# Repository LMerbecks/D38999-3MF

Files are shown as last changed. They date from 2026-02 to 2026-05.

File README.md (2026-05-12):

# D38999-3MF

Mated connector system shell size C

In this repository we developed a MIL-DTL-38999 style
connector system that can be 3D-printed. It was inspired by
[this thing](https://www.thingiverse.com/thing:3129731) by
[fdavies](https://www.thingiverse.com/fdavies/designs). The
connector system uses Molex
[1561](https://www.molex.com/en-us/products/series-chart/1561)
and
[1560](https://www.molex.com/en-us/products/series-chart/1560)
stamped circular crimp contacts. 
> Note this connector system
does not claim full compatibility and compliance with the
standards mentioned. 

## Introduction

MIL-DTL-38999 connectors are widely adopted in the aerospace
industry. You may take a look at the different variants at
leading manufacturers like [Amphenol
Aerospace](https://www.amphenol-aerospace.com/products/mil-dtl-38999-connectors)
or [ITT Cannon](https://www.ittcannon.com/38999-style). A
really common type is the type III variant which features a
triple start thread for mating.

These connectors are durable,
[scoop-proof](https://www.microwaves101.com/encyclopedias/scoop-proof-connectors)
and satisfying to work with. However, they are also
expensive and thus not an option for small or hobby
projects. This project aims to change that by making these
connectors accessible to a broader audience via additive
manufacturing. Surely these versions will never match the
characteristics of the industrial versions but they make the
D38999 concept with almost all advantages accessible to more people than just industry
branches. 

## Specifications and Features

- 336 unique connector systems in nine different sizes
- M3 bolt holes for mounting of receptacle
- Polarized and scoop proof
- Up to 61 contacts per connector
- 1.25 turns to fully lock
- cheap and accessible contacts <0.10€ per contact
- mated length 30mm
- max footprint 46 x 46 mm

## Usage

A connector system consists of a receptacle and a plug. You
can mate the plug to the receptacle by turning the plug on
the receptacle until the keys align. The connectors should
move closer together at that point. Then you pull the
connection closed by rotating the coupling nut on the plug
clockwise. Turn the coupling nut until the groove on the
receptacle is covered by the nut. To release the connector rotate the coupling nut
counter-clockwise.

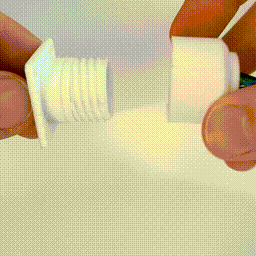
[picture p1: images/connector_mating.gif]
Animation showing mating of connectors


*Animation of
connectors mating*

To build a connector system you have to 
1. choose shells, and
2. choose an insert arrangement. 

We will go into more detail of these two steps in the
following sections.

### Shells

Shells are the frames of the connector system that in turn
hold the fixture (insert) that locates the electrical
contacts. They are the outermost part of the connector and
thus are called shells. Their primary function is the
mechanical mating.

The shells are characterized by part numbers in this format:

`D38999-<ST>A<S><XXX><K>`
where
- `D38999` is the connector series code,
- `<ST>` is the shell type,
- `A` is the service class for additive manufacturing
  (choosen by us)
- `<S>` is the size code,
- `<XXX>` is the insert arrangement identifier, and
- `<K>` is the keying code.

The individual parts for the part number are addressed int
he following sections

#### Shell types

There are two shell types supported at the moment: 
- straight plugs (code `26`)
  Straight plug part code D38999-26ACXXXN *A D38999-26ACXXXN
  shell*
- wall mount receptacles (code `20`)
  Wall mount receptacle part code D38999-20ACXXXN *A
  D38999-20ACXXXN shell*
  
#### Shell sizes

The shell size determines only the diameter of a
shell. The length i.e. the dimension in direction of the
mating axis is not affected by this. 

The available shell sizes are listed in the following table.
Note that there are military and civil codes for the shell
size. For the shells the military code is used in this repository.

| military code | `A` | `B` | `C` | `D` | `E` | `F` | `G` | `H` | `J` |
| ---| - | - | - | - | - | - | - | - | - |
| civil code |` 9` | `11` | `13` | `15` | `17` | `19` | `21` | `23` | `25` |

Shell size B and C plugs*Different shell size
plugs: size B on the left and size C on the right*

In general larger connectors can hold inserts with more electrical contacts.

#### Shell keying

Shells of the same size can have different keying options.
Only plugs and receptacles with matching **keying options and
shell sizes** can
mate.

This mechanically prevents mating of wrong connector pairs.
The behavior is achieved by having five keys or keyways around the plug
or receptacle, respectively, in a unique pattern for every
keying option. Note that the exact pattern can also change depending
on the shell size.

The available keying options are: 

`N, A, B, C, D, E`

Here option `N` is the most common "normal" option.

#### Building shell part numbers

In conclusion, to build a shell part number you 
1. select the shell type,
2. select the shell size,
3. select the shell keying.

The CAD models for the shells are found in the `/models/`
directory. They are modeled using [FreeCAD](https://www.freecad.org).

### Inserts

Inserts are the inner parts of the connector system that
locate the electrical contacts. The insert arrangement part
numbers look like this:

`<SZ>-<IA><G>` where
- `<SZ>` is the shell size, 
- `<IA>` is the insert arrangement, and
- `<G>` is the gender.

#### Shell size

The shell size determines which shell sizes the insert can
be used with. It primarily determines the outside diameter
of the insert. 

All shell sizes have at least two insert arrangements
available right now.

#### Insert arrangement

The insert arrangement determines how the contacts are
arranged in the insert. The code hints how many contacts
can find place in a insert. This is not always the case.

The following insert arrangements (combined with the shell
size) are available

| Insert Arrangement Name | Number of contacts | Tested |
|---|---| --- |
| 9-3 | 3 | :white_check_mark: |
| 9-98 | 3 | :white_check_mark: |
| 11-2 | 2 | :white_check_mark: |
| 11-4 | 4 | :white_check_mark: |
| 11-5 | 5 | :white_check_mark: |
| 11-98 | 6 | :white_check_mark: |
| 11-99 | 7 | :white_check_mark: |
| 13-4 | 4 | :white_check_mark: |
| 13-8 | 8 | :white_check_mark: |
| 13-98 | 10 | :white_check_mark: |
| 15-5 | 5 | :white_check_mark: |
| 15-15 | 15 | :white_check_mark: |
| 15-18 | 18 | :white_check_mark: |
| 15-19 | 19 | :white_check_mark: |
| 15-97 | 12 | :white_check_mark: |
| 17-6 | 6 | :x: |
| 17-8 | 8 | :x: |
| 17-11 | 11 | :x: |
| 17-26 | 26 | :x: |
| 19-11 | 11 | :x: |
| 19-28 | 28 | :x: |
| 19-30 | 30 | :x: |
| 19-32 | 32 | :x: |
| 21-11 | 11 | :x: |
| 21-16 | 16 | :x: |
| 21-24 | 24 | :x: |
| 21-25 | 25 | :x: |
| 21-27 | 27 | :x: |
| 21-29 | 26 | :x: |
| 21-39 | 39 | :x: |
| 21-75 | 4 | :x: |
| 21-76 | 4 | :x: |
| 23-21 | 21 | :x: |
| 23-32 | 32 | :x: |
| 23-34 | 34 | :x: |
| 23-36 | 36 | :x: |
| 23-53 | 53 | :x: |
| 23-55 | 55 | :x: |
| 23-97 | 16 | :x: |
| 23-99 | 11 | :x: |
| 25-4 | 56 | :x: |
| 25-8 | 8 | :x: |
| 25-10 | 8 | :x: |
| 25-11 | 11 | :x: |
| 25-19 | 19 | :x: |
| 25-20 | 30 | :x: |
| 25-21 | 30 | :x: |
| 25-24 | 24 | :x: |
| 25-29 | 29 | :x: |
| 25-37 | 37 | :x: |
| 25-43 | 43 | :x: |
| 25-46 | 46 | :x: |
| 25-47 | 46 | :x: |
| 25-61 | 61 | :x: |
| 25-90 | 46 | :x: |
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

Where possible standard insert arrangements are used as
specified in MIL-STD-1560C.

Not all inserts have been tested yet. Feel free to
contribute here.

#### Gender

The gender determines whether the insert is designed to hold
pin contacts (Molex 1560, code `P`) or socket contacts
(Molex 1561, code `S`). 

This impacts the length of the insert but any gender of
insert can be installed in any receptacle or plug as long as
the shell size matches. 

In general, the plug that can be moved around gets the socket insert because these
contacts are less exposed and less prone to damage. The
receptacle receives the pin insert.

#### Building insert part numbers

In conclusion, to build a part number of an insert you need
to
1. choose the shell size, 
2. choose how many contacts you need,
3. choose the gender.

Most of the time you'll want to get both genders of an
insert, however.

Insert are automatically generated through scripts located
in `/scripts/`. The base models are designed in
[FreeCAD](https://www.freecad.org) and are located in `/models/` 

## Manufacturing and Assembly

There are a few important notices you should follow when
building your connector system. These steps are described in
the following section.

### Manufacturing

[Download](https://www.printables.com/@leandermerbe_4394823/collections/3171811) or [export](/scripts/) the model files and slice them. We had
good results with 0.2mm layer height. Print the shells in
the orientation shown in the figure below.

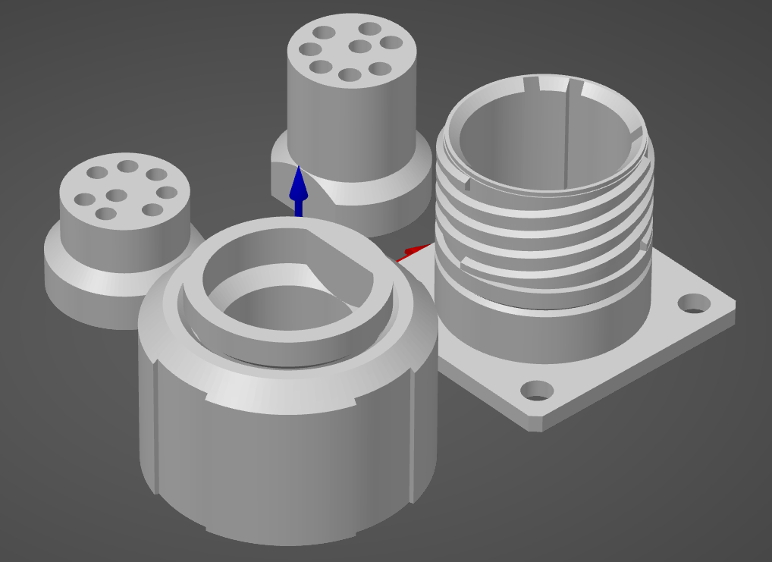
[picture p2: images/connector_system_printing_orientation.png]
Print orientation shells
*Recommended
printing
orientation for plug, receptacle, and inserts.*

The plug is a two body part that is print in place.

> **IMPORTANT**
> 
> Disable support generation for the plug shell. You will
> not be able to remove the support.

The print time varies and can take up to multiple hours.

### Assembly

After the print is finished remove the parts. You can now
turn the coupling nut on the plug shell to break it loose
from the core. If this does not work right away you can use
a matching receptacle to fix the core in place and get a
better grip on it. 

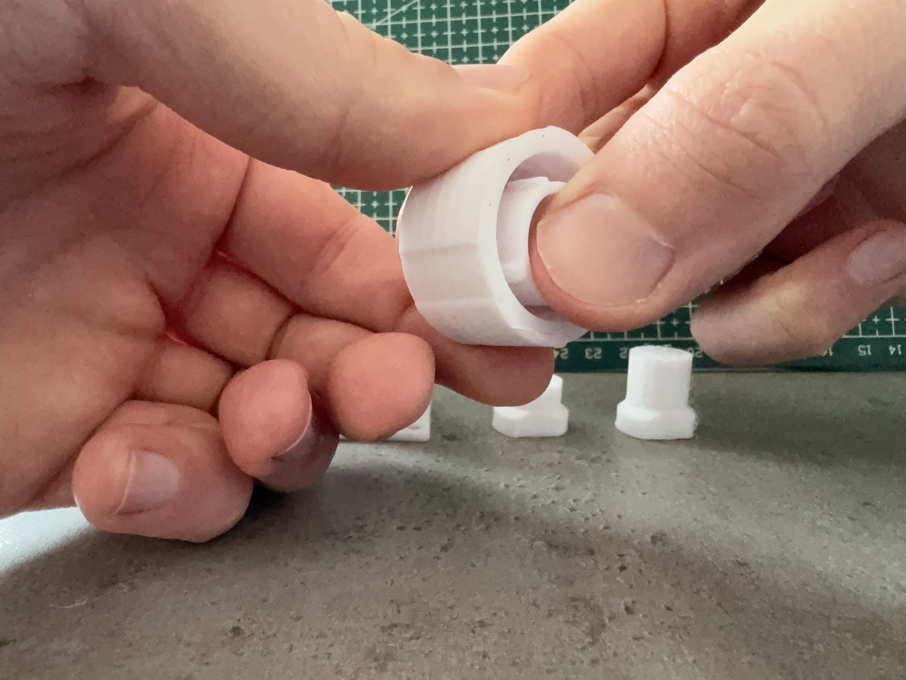
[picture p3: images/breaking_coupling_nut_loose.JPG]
Breaking the coupling nut of the plug loose
*Breaking the
coupling nut loose from the plug core.*

Now you clean the insert contact holes with a 2mm drill.
This removes any strings or seams formed during
manufacturing. You may use a cordless drill to speed up the
process. 

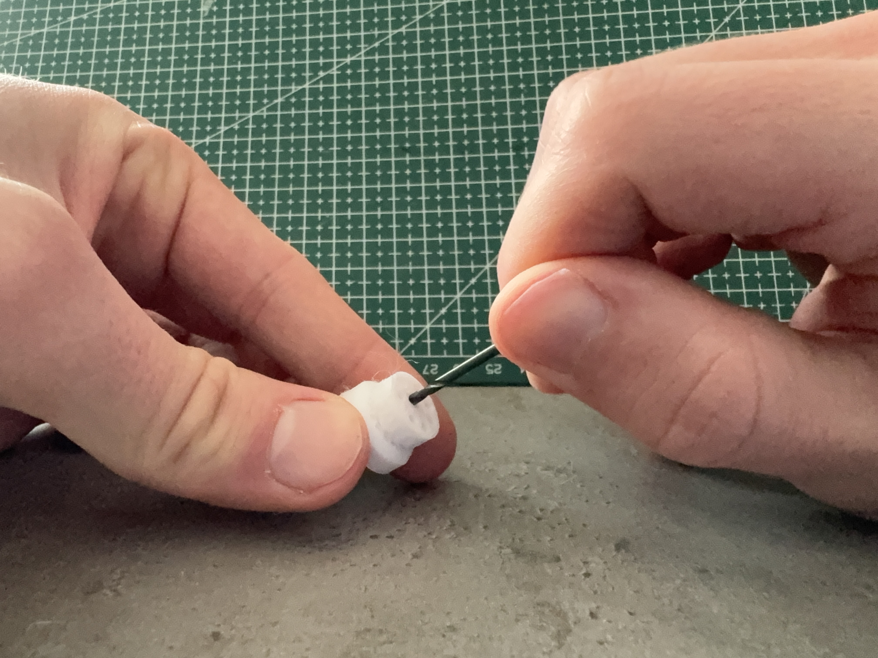
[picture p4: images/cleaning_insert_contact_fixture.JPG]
Cleaning contact holes
*Cleaning
the contact holes with a 2mm drill*

Next, insert the inserts into the shells. Depending on the
fit you may want to glue them in permanently with superglue
or shim them with e.g. a piece of paper.

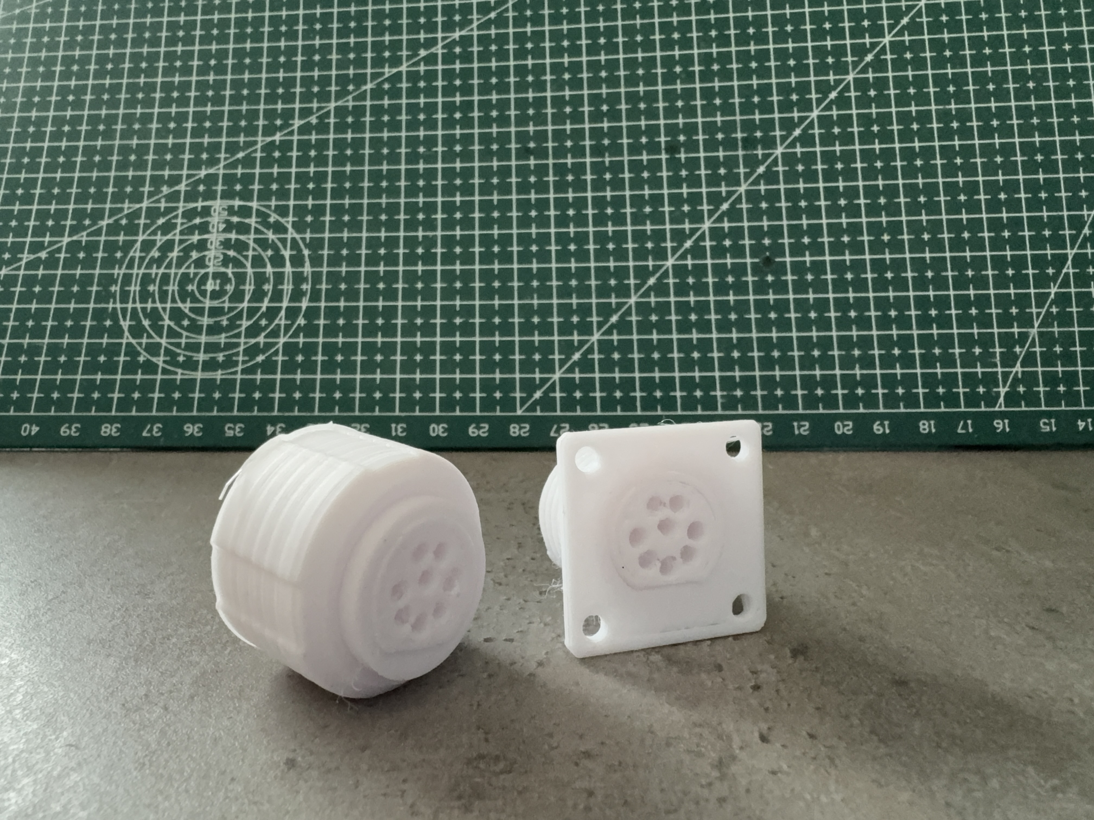
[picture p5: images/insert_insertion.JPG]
Insertion of inserts
*Insertion of inserts*

Afterward, crimp the cables/wires with the Molex 1560 or
1561 contacts and insert the contacts into the appropriate
insert depending on the gender. You may use a pair of pliers
here to exert more force but the contact should go in rather
smoothly. Insert the contacts into the insert so far that
the contact is just barely inside of the insert.

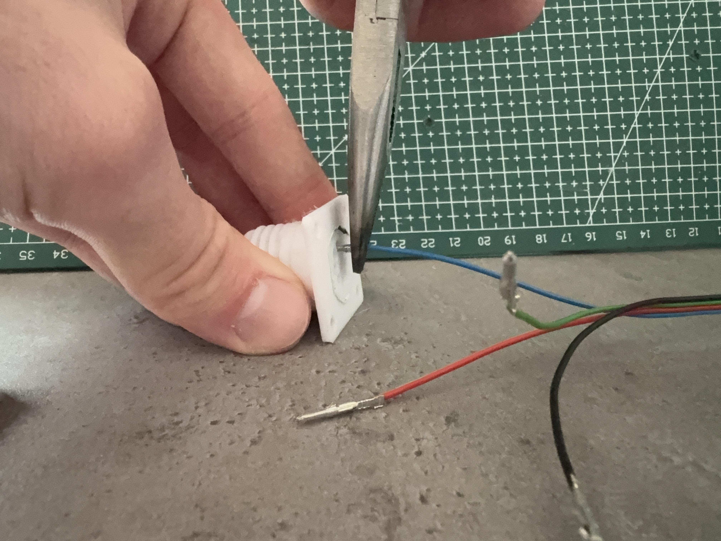
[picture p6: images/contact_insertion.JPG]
Installing the contacts

*Installing crimp contacts*

At last, you have your completed connector system:
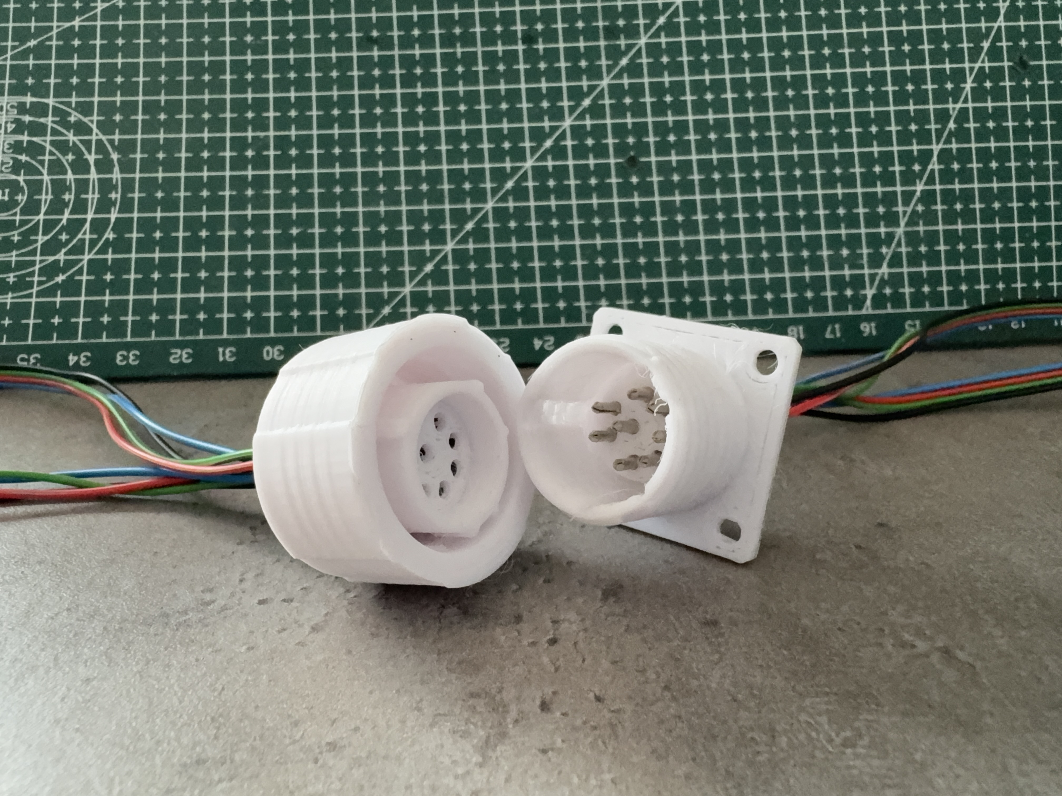
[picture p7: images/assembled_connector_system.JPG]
Completed connector system
*Completed
connector system*

## Developer Instructions

So you want to have a deeper look into this repository and
how the CAD files are working? We look at three parts here
1. the CAD files,
2. exporting the models, and
3. generating inserts.

### CAD files

The CAD files are developed with
[FreeCAD](https://www.freecad.org/) and split into only four
files
1. a file for the receptacle `/models/D38999-26AXXXXX.FCStd`,
2. a file for the plug `/models/D38999-20AXXXXX.FCStd`,
3. a file for the pin inserts `/models/PinInserts.FCStd`, and 
4. a file for the socket inserts. `/models/SocketInserts.FCStd`

Historically, the receptacle and plug files contained the
geometry of the inserts. When automation was deployed in
the insert generation this was changed.

The models are parametrized and the shell size and keying
option can be changed by accessing the corresponding attributes of the
`Receptacle_core` or `Plug_core` parts in the property
inspector. Note that keying options vary for shell sizes and
are thus given with the keying code and all applicable shell
sizes afterward. 

The insert models are generated automatically and also
exported in one go. The models for them contain the
base body that fits into the shell and a tool body that is
used to form the contact fixtures for all inserts. 

### Export

As there are a lot of geometries to export, this process is
automated with scripts located in `/scripts/`. The export is split into different procedures for
inserts and shells. It uses python and the python interface
of FreeCAD. Before starting you need to install
dependencies: 
```bash
> cd ./scripts/
> python3 -m venv .venv
> source .venv/bin/activate
> pip install -r requirements.txt 
> # this is for the export using FreeCAD python
> freecad.pip install -r requirements.txt
```

Then you can start the export which is described for shells
and inserts separately.

#### Shells

To export shells we use the `export_shells.py` script. It
changes the keying option and shell size of both shell
models, recomputes the model and exports a `.3mf` to
`/output/`. Note that the export can take up to six minutes.

To run it type:

```bash
> cd scripts
> freecad.cli export_shells.py
```

After the run your output directory should look like this (abbreviated).

```bash
> tree ./output/
./output/
├── plugs
│   ├── A
│   │   ├── D38999-26AAXXXA.3mf
│   │   ├── D38999-26AAXXXB.3mf
│   │   ├── D38999-26AAXXXC.3mf
│   │   ├── D38999-26AAXXXD.3mf
│   │   ├── D38999-26AAXXXE.3mf
│   │   └── D38999-26AAXXXN.3mf
│   ├── B
│   │   └── ...
│   ├── C
│   │   └── ...
│   ├── D
│   │   └── ...
│   ├── E
│   │   └── ...
│   ├── F
│   │   └── ...
│   ├── G
│   │   └── ...
│   ├── H
│   │   └── ...
│   └── J
│   │   └── ...
└── wall_mount_receptacles
    ├── A
    │   ├── D38999-20AAXXXA.3mf
    │   ├── D38999-20AAXXXB.3mf
    │   ├── D38999-20AAXXXC.3mf
    │   ├── D38999-20AAXXXD.3mf
    │   ├── D38999-20AAXXXE.3mf
    │   └── D38999-20AAXXXN.3mf
    ├── B
    │   └── ...
    ├── C
    │   └── ...
    ├── D
    │   └── ...
    ├── E
    │   └── ...
    ├── F
    │   └── ...
    ├── G
    │   └── ...
    ├── H
    │   └── ...
    └── J
        └── ...
```

The geometries are exported sorted by shell type, shell size
and then keying option. 

#### Inserts

The insert export is a two step process. First the
dimensions are extracted from the MIL-STD-1560 pdf. This is
done with python via the following command. It may take a
few minutes to run. 

```bash
> cd scripts
> python3 extract_dimension_tables.py
```
The script scans the standard for any inserts for the D38999
Series III connectors that have no contacts smaller than
size 20. This ensures the Molex 1560 and 1561 contacts fit
into the insert. 

After the command the `/dimensions/` directory should
look like this:

```bash
tree dimensions/
dimensions/
├── 11-2_contact_positions.csv
├── 11-4_contact_positions.csv
├── ...
├── applicable_insert_arrangements.csv
├── MIL-STD-1560C_CHG-2.pdf
└── overview.csv
```

The `*_contact_positions.csv` files contain the positions
for the contacts of every insert-arrangement. The
`applicable_insert_arrangements.csv` is a simple list of all
insert arrangements that are available for this connector
series. Likewise `overview.csv` lists the available insert
arrangements with the available amounts of contacts, as in
the table above. 

Next, the FreeCAD CLI is used to generate all inserts that
are in the `dimensions` directory. Note that you may define
custom insert arrangements with unique file names following
the naming convention. This script can take a few minutes to
run. 

```bash
> cd scripts
> freecad.cli insert_generator.py
```

Now the `output` directory should contain all exported
insert models. 

```bash
> tree output
output
└── inserts
    ├── A
    │   ├── 9-3P.3mf
    │   ├── 9-3S.3mf
    │   ├── 9-98P.3mf
    │   └── 9-98S.3mf
    ├── B
    │   └── ...
    ├── C
    │   └── ...
    ├── D
    │   └── ...
    ├── E
    │   └── ...
    ├── F
    │   └── ...
    ├── G
    │   └── ...
    ├── H
    │   └── ...
    └── J
        └── ...
```

## Credits

This project was inspired by [this
thing](https://www.thingiverse.com/thing:3129731) by
[fdavies](https://www.thingiverse.com/fdavies/designs).
Though the models have been developed independently and the
features have been radically altered.

The standards used for design are 
- [MIL-DTL-38999](http://everyspec.com/MIL-SPECS/MIL-SPECS-MIL-DTL/MIL-DTL-38999M_AMENDMENT-2_57021/)
    - [MIL-DTL-38999/20](https://everyspec.com/MIL-SPECS/MIL-SPECS-MIL-DTL/MIL-DTL-38999_20G_AMENDMENT-2_42842/)
    - [MIL-DTL-38999/26](https://everyspec.com/MIL-SPECS/MIL-SPECS-MIL-DTL/MIL-DTL-38999_26E_302/) 
- [MIL-STD-1560](http://everyspec.com/MIL-STD/MIL-STD-1500-1599/MIL-STD-1560C_CHG-2_56319/)
 
## License

This work is licensed under [CC BY-NC-SA
4.0](https://creativecommons.org/licenses/by-nc-sa/4.0/deed.de).
See `LICENSE`for complete license text.

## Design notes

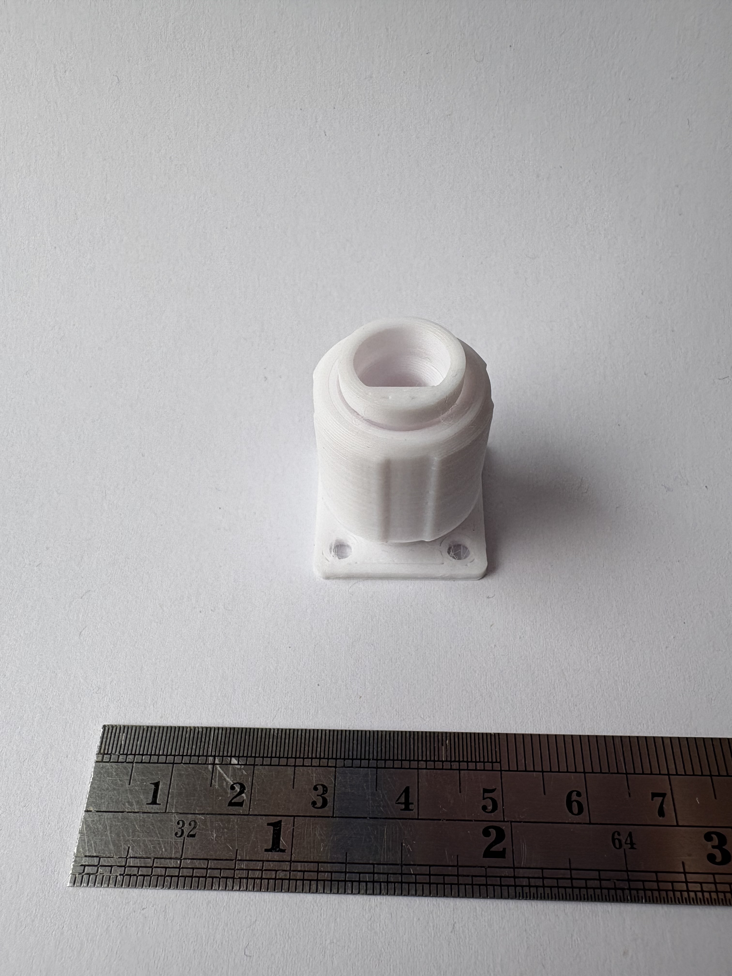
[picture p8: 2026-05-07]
images/A_Shells_mated.jpeg

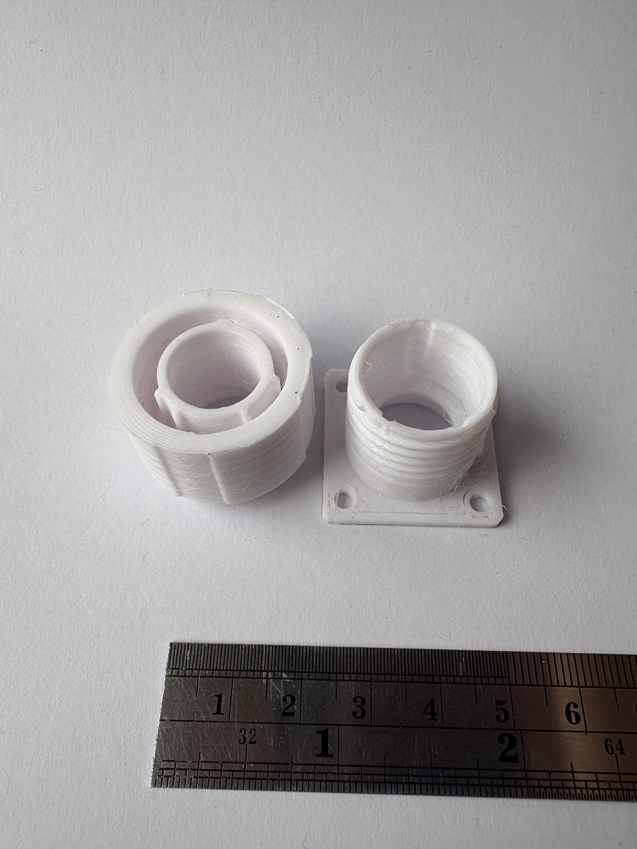
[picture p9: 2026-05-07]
images/C_Shells_disconnected.jpeg

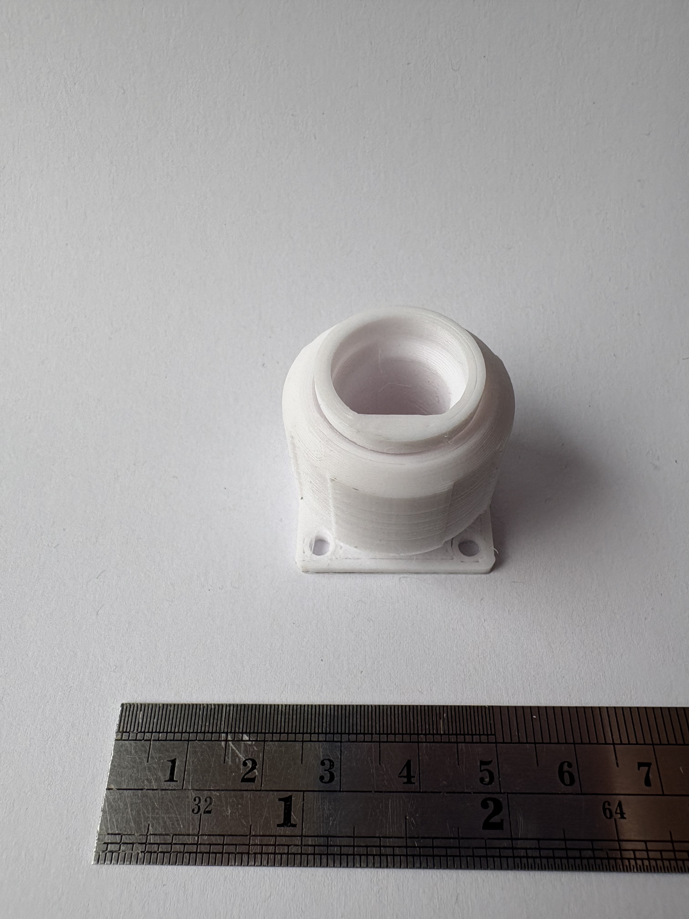
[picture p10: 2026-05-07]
images/C_Shells_mated.jpeg

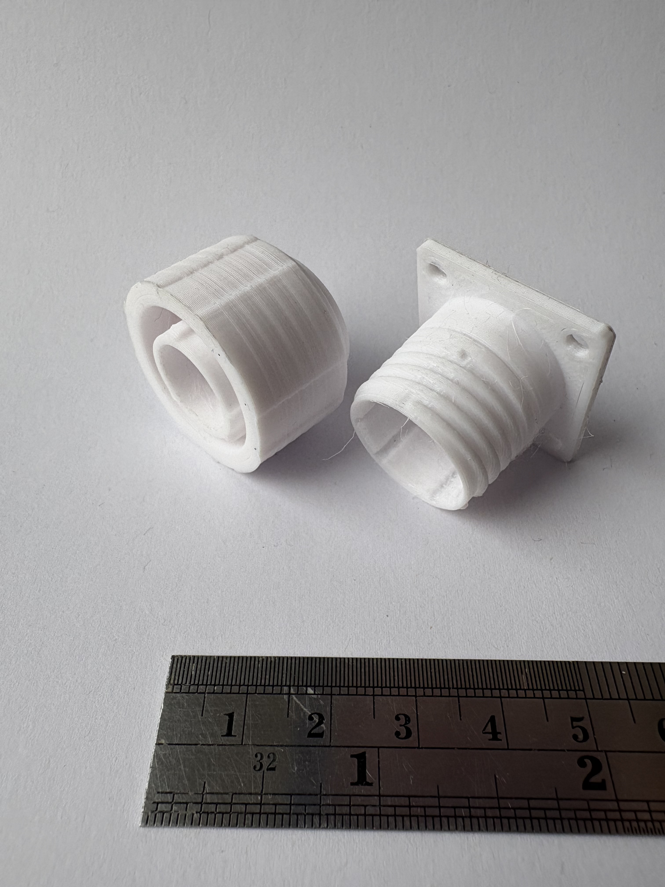
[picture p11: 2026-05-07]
images/C_Shells_isometric.jpeg

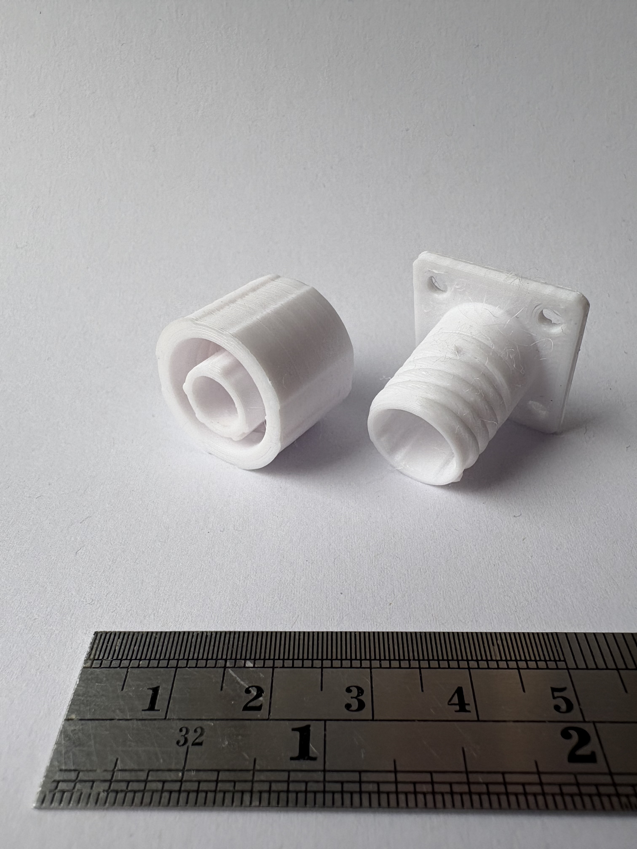
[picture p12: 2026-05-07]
images/A_Shells_isometric.jpeg

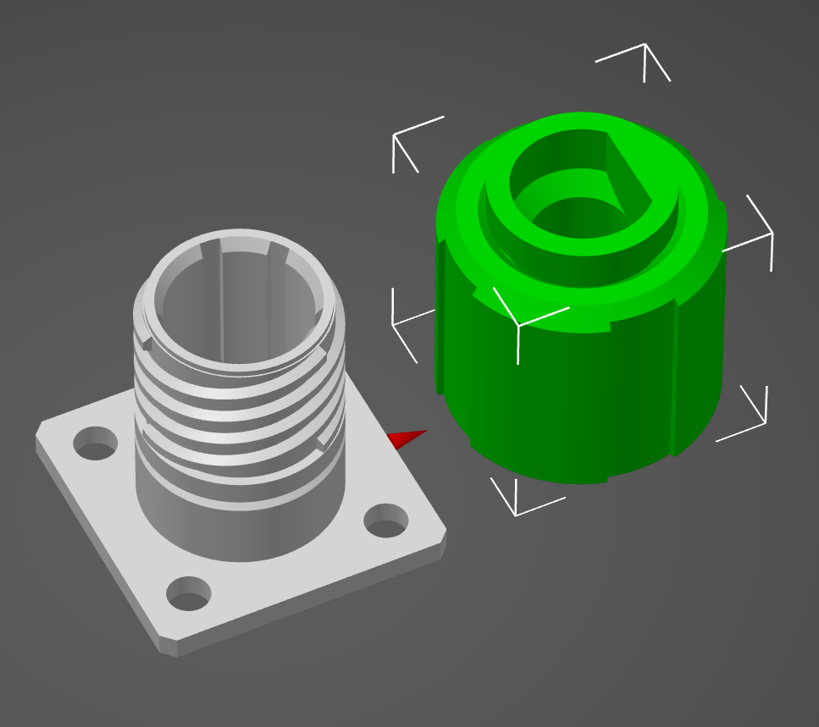
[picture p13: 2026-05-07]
images/A_Shells_Orientation.png

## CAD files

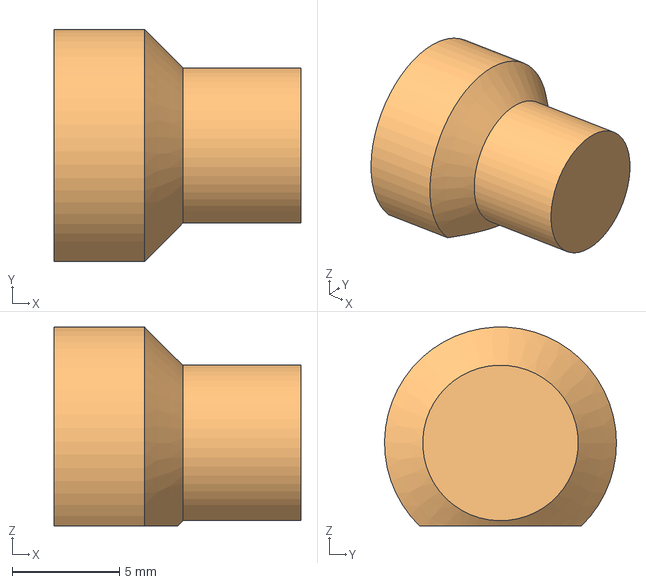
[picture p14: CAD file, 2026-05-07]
models/PinInserts.FCStd
11.5 x 10.8 x 9.25 mm
ContactFixtureTool
SizeAInsertDummy

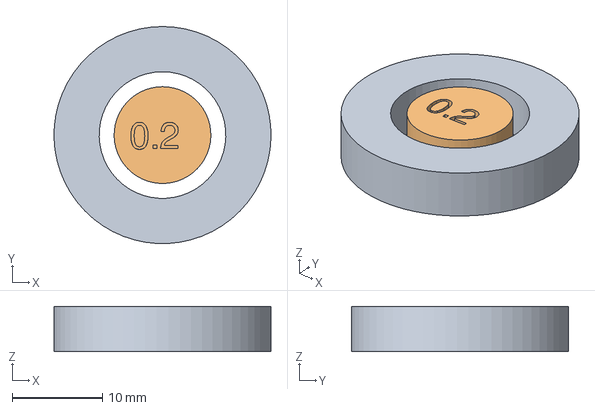
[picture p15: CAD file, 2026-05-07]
tests/insert_tolerance_test.FCStd
24.0 x 24.0 x 5.00 mm
Sleeve
Arbor

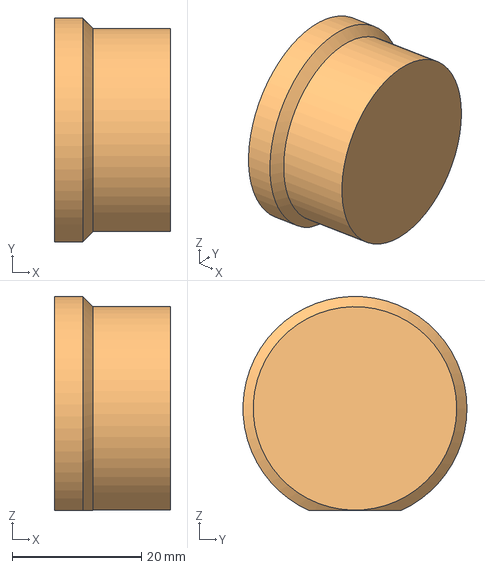
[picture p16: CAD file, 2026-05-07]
models/SocketInserts.FCStd
18.0 x 34.7 x 33.1 mm
ContactFixtureTool
SizeJInsertDummy

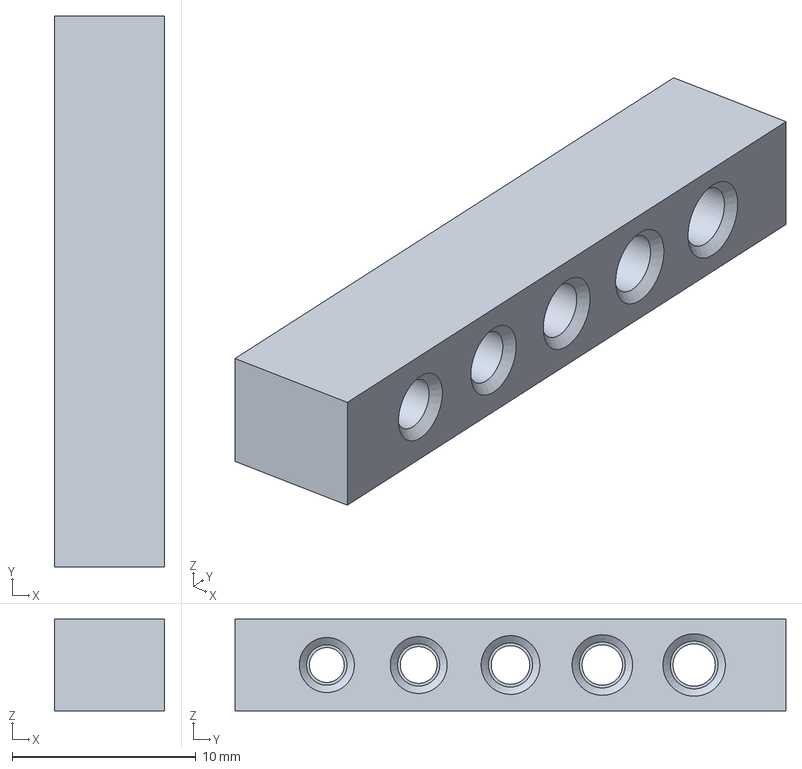
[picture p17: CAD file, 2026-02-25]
tests/insert_fixture_test.FCStd
6.00 x 30.0 x 5.00 mm

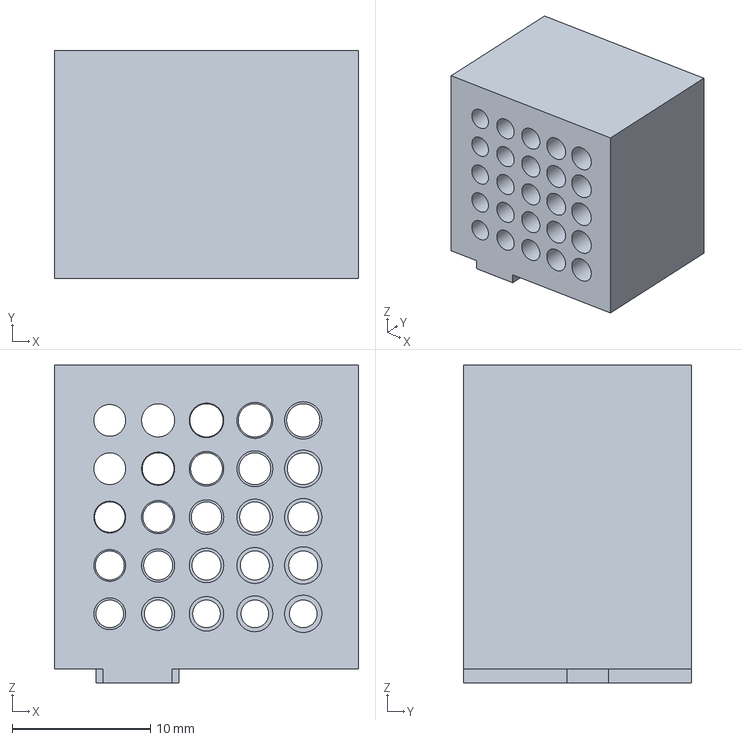
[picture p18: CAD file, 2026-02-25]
tests/female_contact_fixture_test.FCStd
22.0 x 16.5 x 23.0 mm

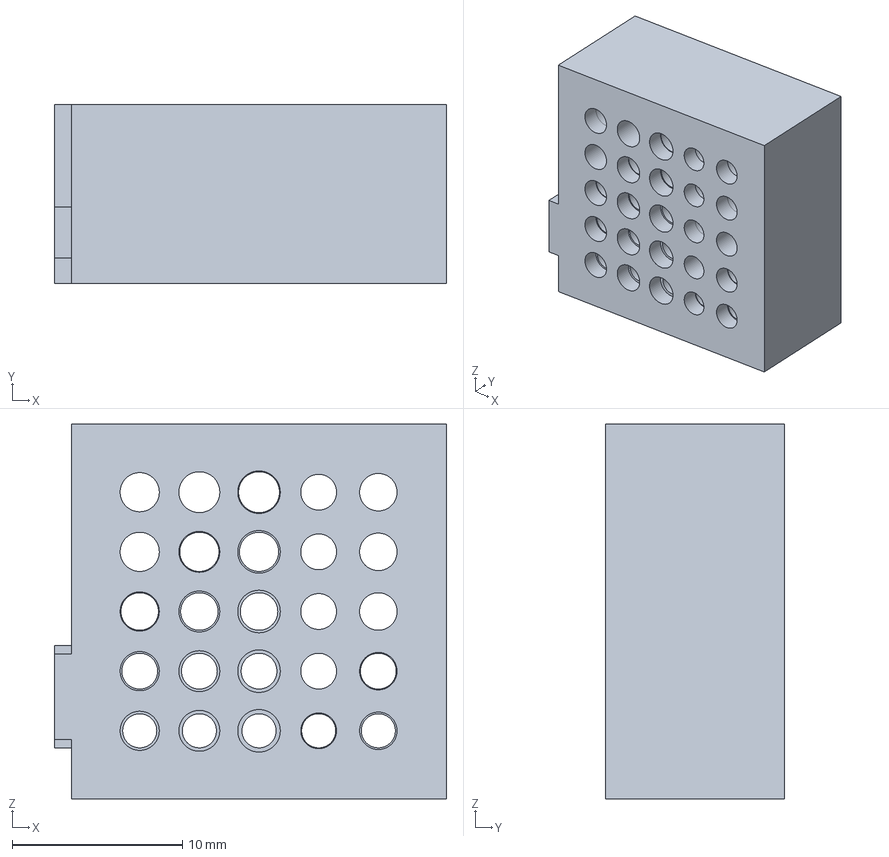
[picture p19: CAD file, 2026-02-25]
tests/male_contact_fixture_test.FCStd
23.0 x 10.5 x 22.0 mm

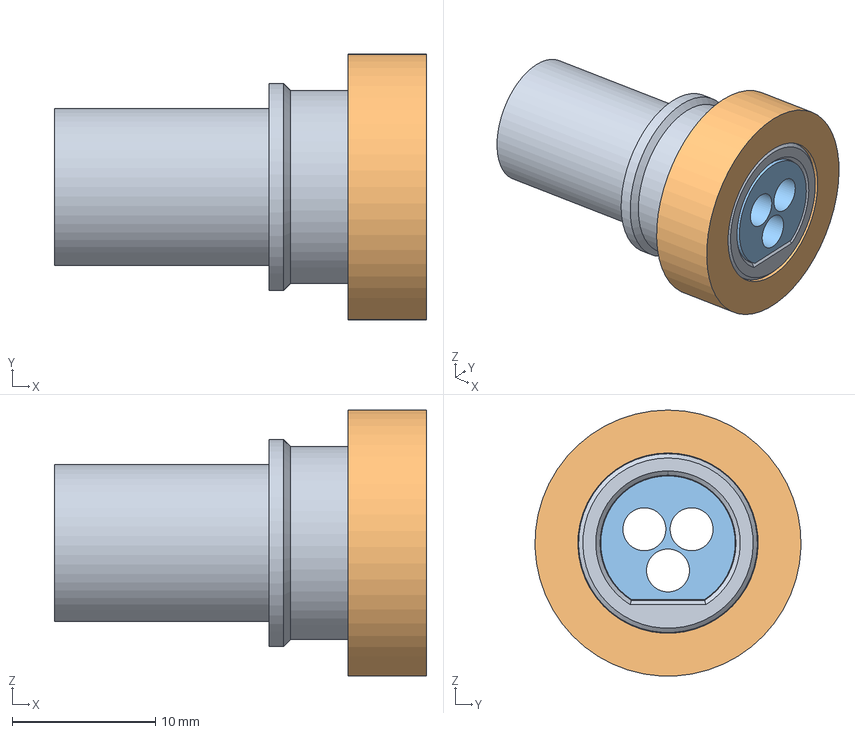
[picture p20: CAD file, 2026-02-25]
tests/axialDetent.FCStd
26.0 x 18.6 x 18.6 mm
Core
DetentRing
Insert_9-98 like

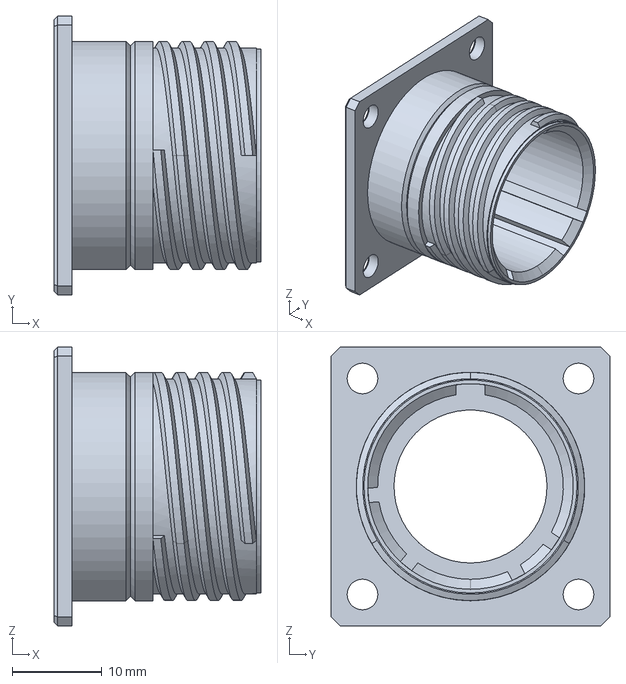
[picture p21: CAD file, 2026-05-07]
models/D38999-20AXXXXX.FCStd
23.0 x 31.0 x 31.0 mm

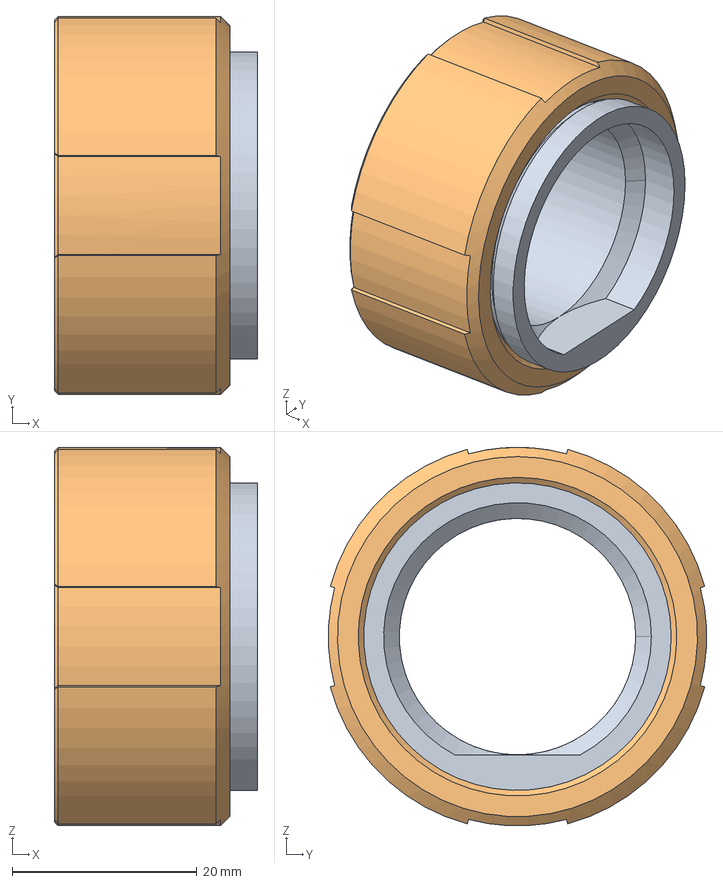
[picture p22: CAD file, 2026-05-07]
models/D38999-26AXXXXX.FCStd
22.0 x 40.9 x 41.0 mm
Core
Coupling Nut

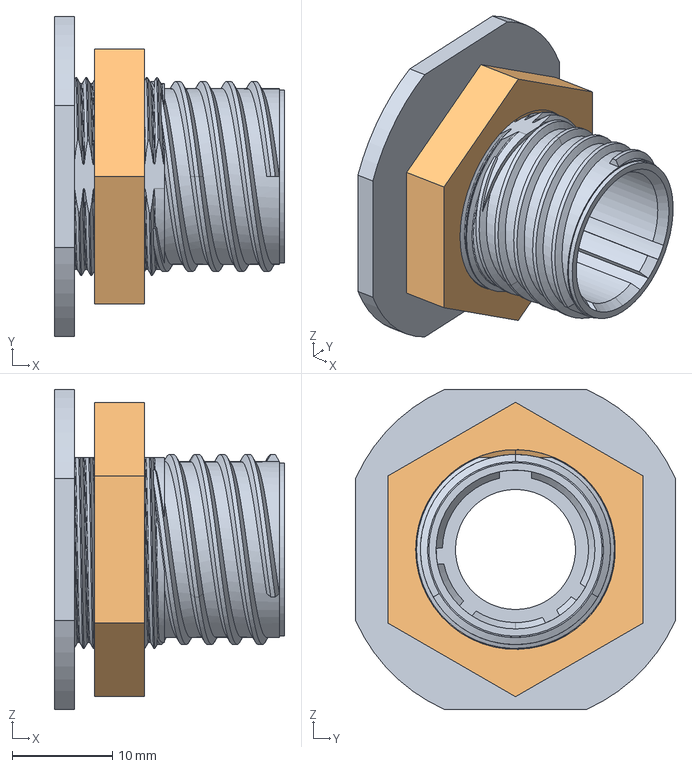
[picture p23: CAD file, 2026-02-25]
models/D38999-24AXXPX.FCStd
23.0 x 32.0 x 32.0 mm
Core
JamNut

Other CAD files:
models/connector_assembly.FCStd

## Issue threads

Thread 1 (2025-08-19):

Find circular contacts

LMerbecks, 2025-08-19:
For this project to work  we need to find circular contacts (pin and socket contacts) that are cheap and readily available.

We are thinking of molex contacts or similar.

Priority is on crimp contacts at first. Afterward contacts with PCB tails are important as well. The best option would of course be a contact series that is available both in crimp and THT versions.

LMerbecks, 2025-08-20:
I came across this [thing](https://www.thingiverse.com/thing:2755931) by [fdavies](https://www.thingiverse.com/fdavies/designs). He actually did a [38999](https://www.thingiverse.com/thing:3129731) version but only in one shell size and one insert arrangement.

For the former thing he used Molex contacts from the 062 connector series:
- Female contacts: [02-06-1103](https://www.molex.com/en-us/products/part-detail/02061103), [datasheet](https://www.molex.com/en-us/products/part-detail/02061103?display=pdf), [buy for 0.10€](https://www.mouser.de/ProductDetail/Molex/02-06-1103?qs=359VwiUTsp0rVi3UDduwvw%3D%3D)
- Male contacts: [02-06-2103](https://www.molex.com/en-us/products/part-detail/02062103), [datasheet](https://www.molex.com/en-us/products/part-detail/02062103?display=pdf), [buy for 0.11€](https://www.mouser.de/ProductDetail/Molex/02-06-2103?qs=clwyIdmhKqXyNQ5%2Fp50i5g%3D%3D)

Drawings and 3D models are also available on the website. The price is pretty competitive. I think having the contacts sit in the insert arrangement properly might be a problem but I think we will go with these contacts at first.

We should order some to have at hand for measurements and testing.

Closed 2025-08-20.

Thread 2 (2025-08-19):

Find dimensions of shells

LMerbecks, 2025-08-19:
The military standard that defines the connector system -  MIL-DTL-38999M - is [publicly available](http://everyspec.com/MIL-SPECS/MIL-SPECS-MIL-DTL/MIL-DTL-38999M_AMENDMENT-2_57021/). In here the dimensions for the different types of shells should be defined. Go search them and document where to find them in this issue.

Drawings should be attached here (and referenced) to show which dimensions to use.

# Shell styles

There are multiple styles of connector shell styles:

1. Straight Plugs: These are the most used connectors that are found on cables most of the time. They have a nut permanently attached which provides the mating force.
2. Cable Receptacle: These are not so commonly found because the receptacle are usually mounted on equipment. This is the exact negative to the straight plug.
3. Wall mount receptacle: Receptacle that is mounted to a wall via a four hole flange
4. Box mount receptacle: Similar to the wall mount receptacle but with minimal protrusion into the box it is mounted on.
5. Jam nut receptacle: Very popular receptacle that can be mounted into thin walls. It uses a jam nut to secure in place.
6. Angled plugs: like a straight plug but with a 90 degree bend.

Additionally, the receptacles are also available in stand-off versions. They are then used with PCB contacts. The stand-off is a way of reducing bending loads on the PCB that would otherwise result from attaching the PCB only with the THT solder pads.

We prioritize the connector styles like this:
1. Straight plug
2. Wall mount receptacle
3. Box mount receptacle
4. Jam nut receptacle
5. Cable receptacle
6. Angled plugs
7. Stand-off receptacles.

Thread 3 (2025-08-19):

Find dimensions of insert arrangments

LMerbecks, 2025-08-19:
Insert arrangements refer to the way the contacts are arranged within the mated face of the connector shells. Similar to #2 the insert arrangement dimensions should also be listed in the [standard](http://everyspec.com/MIL-SPECS/MIL-SPECS-MIL-DTL/MIL-DTL-38999M_AMENDMENT-2_57021/).

To look at the different arrangements in a user friendly way you may turn to [pp. 8 of the Amphenol 38999 catalog](https://www.amphenol-aerospace.com/resources/literature/view/38999-catalog).

For no other reason other than that we think these are the most popular inserts we should try to model the XX-35 arrangements first.

LMerbecks, 2025-08-19:
Alright [MIL-STD-1560C_CHG-2 (instant download link)](http://everyspec.com/MIL-STD/MIL-STD-1500-1599/download.php?spec=MIL-STD-1560C_CHG-2.056319.pdf) 5.1.b defines that all of the shown insert arrangement drawings are showing the front of the pin insert (so the one for the male contacts). The socket inserts are mirrored.

Contact cavity dimensions are defined in 5.1.c (table). Though it remains to be seen if these will be usable with the contacts we find as result of #1.

The locations of the individual 35 insert arrangements can be found in the figures of the following pages. Table II on page 14 offers a hyperlink to the features.

| Insert arrangement | Figure | Page |
| ------ | ---- | ----- |
| 9-35 | 1 | 18 |
| 11-35 | 2 | 26 |
| 13-35 | 3 | 34 |
| 15-35 | 4 | 44 |
| 17-35 | 5 | 59 |
| 19-35 | 6 | 73 |
| 21-35 | 7 | 93 |
| 23-35 | 8 | 112 |
| 25-35 | 9 | 152 |

LMerbecks, 2025-08-19:
# 9-35

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

# 11-35

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

# 13-35

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

# 15-35

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

# 17-35

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

# 19-35

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

# 21-35

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

# 23-35

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

# 25-35

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

Alright should be clear... closing this issue

Closed 2025-08-19.

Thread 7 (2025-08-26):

Design inserts

LMerbecks, 2025-08-26:
The contacts should arrive soon. As soon as they do take dimensions (or use the 3D models for the [02061103](https://www.molex.com/en-us/products/part-detail/02061103) and [02062103](https://www.molex.com/en-us/products/part-detail/02062103)). Remember to use insert arrangements from the standard (see #2).

Note that we realized arrangement 35 probably will not work. For shell 9-98 worked but this was using approximate dimensions. So we should look at inserts for no. 20 contacts.

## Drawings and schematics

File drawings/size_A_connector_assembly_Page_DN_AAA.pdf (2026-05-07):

A | A

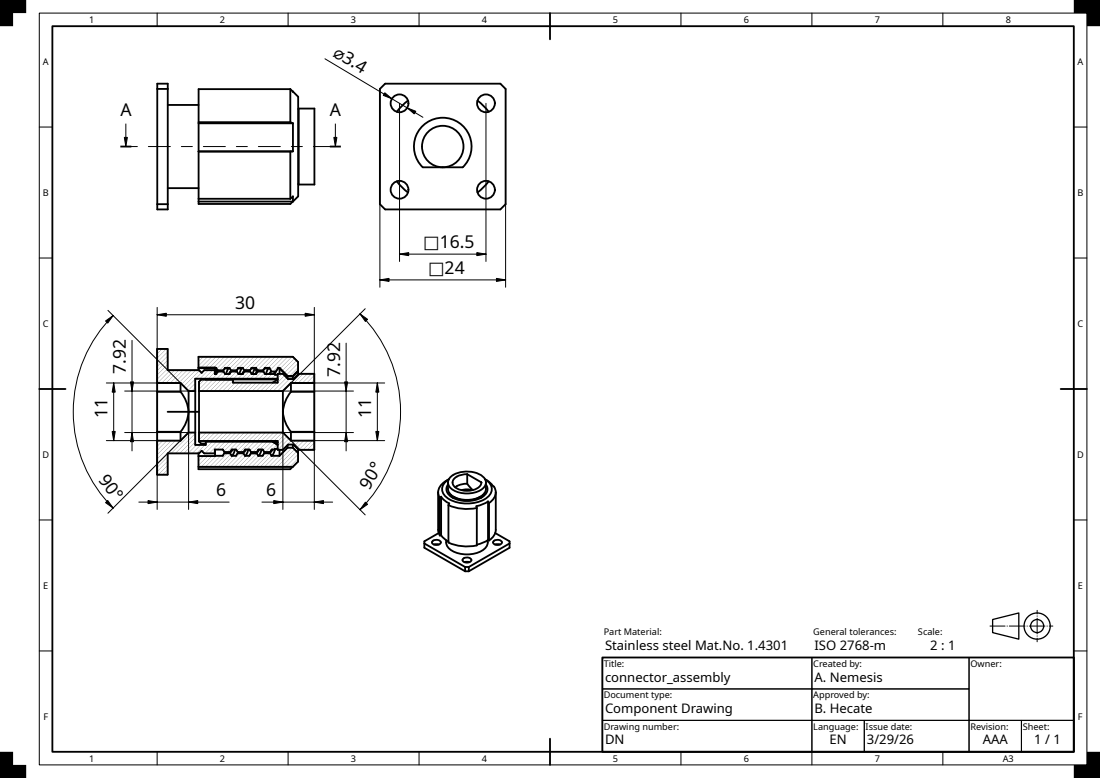
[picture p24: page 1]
Owner:; Drawing number:; Language: Issue date:; Revision: Sheet:; Title:; Approved by:; Created by:; Document type:; Part Material:; General tolerances:; Scale:; AAA; connector_assembly; B. Hecate; A. Nemesis; Component Drawing; Stainless steel Mat.No. 1.4301; ISO 2768-m

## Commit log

2025-08-20 Started CAD design of receptacle. Threads unclear, keyways missing. See #4
    [D38999-20XAXXN.FCStd]
2025-08-23 Completed prototype of box mount receptacle. See #4
    [D38999-20XAXXN.FCStd]
2025-08-23 Added plug file. Fixed git ignore
    [D38999-26XAXXN.FCStd]
2025-08-23 Renamed receptacle to correct part number (it is a pin receptacle and that matters)
    [D38999-20XAXPN.FCStd]
2025-08-23 ignoring 3mf files. Completed straight plug.
    [D38999-26XAXXN.FCStd]
2025-08-23 Updated naming of body
    [D38999-20XAXPN.FCStd]
2025-08-24 Added dimension table with general dimensions and thread dimensions in imperial (and metric)
    [MIL-DTL-38999-III_dimension_table.xlsx]
2025-08-24 forgot to safe. Ready for keying dimensions
    [MIL-DTL-38999-III_dimension_table.xlsx]
2025-08-24 keying parameters transferred. Missing constants from drawings (thread length etc.)
    [MIL-DTL-38999-III_dimension_table.xlsx]
2025-08-24 Started restructuring spreadsheets in parts.
    [D38999-20XAXPN.FCStd]
2025-08-24 Added test parts to test detent idea from #4
    [axialDetent.FCStd]
2025-08-24 I think I broke the model by removing the parameters but that is okay
    [D38999-20XAXPN.FCStd]
2025-08-29 Added main dimension table there should be everything in here
    [MIL-DTL-38999-III_dimension_table.xlsx]
2025-08-29 Added dimensions for three main types of connectors
    [D38999_20AXXPX_Dimensions.xlsx, D38999_24AXXPX_Dimensions.xlsx, D38999_26AXXXX_Dimensions.xlsx]
2025-08-29 Broke the old models
    [D38999-26XAXXN.FCStd, axialDetent.FCStd]
2025-08-29 First fully parametric model need name update as it can now be everything
    [D38999-20XAXPN.FCStd]
2025-09-01 renamed main parts
    [D38999-20AXXPX.FCStd, D38999-20XAXPN.FCStd, D38999-26AXXXX.FCStd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]
2025-09-01 added assembly and tweaked parameters for correct fit.
    [D38999_26AXXXX_Dimensions.xlsx, axialDetent.FCStd, connector_assembly.FCStd]
2025-09-02 added jam nut receptacle with all configurations.
    [D38999-24AXXPX.FCStd]
2025-09-02 updated jam nut receptacle dimensions
    [D38999_24AXXPX_Dimensions.xlsx]
2025-09-02 tweaked existing models
    [D38999-20AXXPX.FCStd, D38999-26AXXXX.FCStd, D38999_26AXXXX_Dimensions.xlsx]
2025-09-07 added connector assembly
    [D38999-20AXXPX.FCStd, D38999-26AXXXX.FCStd, connector_assembly.FCStd]
2025-09-07 basic test to see how contacts fit in different holes
    [insert_fixture_test.FCStd]
2025-09-07 Designed primitive inserts for testing with holes from insert fixture test
    [Pin_Insert.FCStd, Socket_Insert.FCStd]
2025-09-07 created table for documenting dimensions of different insert arrangements
    [D38999_Pin_Insert_Dimensions.xlsx]
2026-01-28 First version of fixture test prints to see what tolerances are best!
    [female_contact_fixture_test.FCStd, male_contact_fixture_test.FCStd]
2026-01-28 Updated fixture test with identifiers and different clearances
    [female_contact_fixture_test.FCStd, male_contact_fixture_test.FCStd]
2026-01-30 Final fixture test pieces
    [female_contact_fixture_test.FCStd, male_contact_fixture_test.FCStd]
2026-01-30 Designed and added insert arrangement with one contact for A shells. Insert body should be exportable for all shell sizes to generate more
    [D38999-20AXXPX.FCStd, D38999-26AXXXX.FCStd, connector_assembly.FCStd]
2026-02-11 Adjusted thread tolerance of coupling nut to 0.1mm. See #8
    [D38999-26AXXXX.FCStd]
2026-02-11 Adjusted coupling nut to plug interface tolerance to 0.6mm. See #9
    [D38999-26AXXXX.FCStd]
2026-02-11 Added inserts for plug. See #7
    [D38999-26AXXXX.FCStd]
2026-02-11 Changed license to CC-BY-NC
    [D38999-26AXXXX.FCStd]
2026-02-11 Added pin inserts and mating indicator to receptacles. See #7 and #10
    [D38999-20AXXPX.FCStd, D38999-26AXXXX.FCStd]
2026-02-12 Increased mating groove depth. See #10. Made pin inserts independent of base configuration.
    [D38999-20AXXPX.FCStd]
2026-02-12 Adjusted jam nut and removed detent groove in core.
    [D38999-24AXXPX.FCStd]
2026-02-12 Made socket inserts mating area longer. See #7.
    [D38999-26AXXXX.FCStd]
2026-02-13 Updated pin inserts so that they match with the socket inserts. Also updated receptacle core. See #14
    [D38999-20AXXPX.FCStd]
2026-02-13 Updated socket inserts and plug core. Removed unnecessary variable from dimensions. See #14
    [D38999-26AXXXX.FCStd]
2026-02-16 Changed configuration table attributes (to make them easier to script and understand). See #16
    [D38999-26AXXXX.FCStd]
2026-02-16 Made receptacle printable without support. Incomplete.
    [D38999-20AXXPX.FCStd]
2026-02-16 Renamed main files to the correct placeholder name.
    [D38999-20AXXXXX.FCStd, D38999-26AXXXXX.FCStd]
2026-02-16 Changed config table attribute names and field entries. See #16
    [D38999-20AXXXXX.FCStd]
2026-02-16 Adapted shells and inserts for better printability.
    [D38999-20AXXXXX.FCStd, D38999-26AXXXXX.FCStd]
2026-02-16 renamed shells for better scripting. See #16
    [D38999-20AXXXXX.FCStd, D38999-26AXXXXX.FCStd]
2026-02-16 Added export function for the inserts. See #16
2026-02-16 Fixed configuration tables using entire table. Increased thread tolerance in coupling nut.
    [D38999-20AXXXXX.FCStd, D38999-26AXXXXX.FCStd]
2026-02-18 Adjusted tolerances for inserts and filled inserts for B shell size. Others pending once issue #19 is resolved.
    [D38999-20AXXXXX.FCStd, D38999-26AXXXXX.FCStd]
2026-02-18 Added test fixtures to adapt inserts. See #19
    [female_contact_fixture_test.FCStd, male_contact_fixture_test.FCStd]
2026-02-18 Transfered fixture tests to B inserts. See #19
    [D38999-20AXXXXX.FCStd, D38999-26AXXXXX.FCStd, female_contact_fixture_test.FCStd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]
2026-02-18 Adapted pin inserts to new contact fixtures
    [D38999-20AXXXXX.FCStd]
2026-02-18 Adapted socket inserts to new contact fixtures. Closes #19
    [D38999-26AXXXXX.FCStd]
2026-02-18 Set visibility of main components to true again
    [D38999-20AXXXXX.FCStd, D38999-26AXXXXX.FCStd]
2026-02-20 Adapted cut of keyways to prevent failure of geometry due to symmetry error.
    [D38999-20AXXXXX.FCStd]
2026-02-20 Completely redefined the sketch for the keyways. No more errors.
    [D38999-20AXXXXX.FCStd]
2026-02-20 Redefined sketch for plug as well to prevent geometry errors due to missing symmetry constraint
    [D38999-26AXXXXX.FCStd]
2026-02-20 made inserts extrusion meet up with the face on the back for 17-18S
    [D38999-26AXXXXX.FCStd]
2026-02-25 Updated README to include comprehensive information on the project.
    [D38999-26AXXXXX.FCStd]
2026-02-25 Added animation of connectors mating.
2026-03-29 Fixed issues from migration to FreeCAD 1.1.0
    [D38999-20AXXXXX.FCStd, D38999-26AXXXXX.FCStd]
2026-03-29 Fixed coupling nut grooves not scaling
    [D38999-26AXXXXX.FCStd]
2026-04-08 fixed errors in export from missing geometry.
    [D38999-20AXXXXX.FCStd, D38999-26AXXXXX.FCStd, connector_assembly.FCStd]
2026-04-12 Added images for printables
    [D38999-20AXXXXX.FCStd, D38999-26AXXXXX.FCStd]
2026-04-12 started making an export script for exporting inserts automatically from csvs
    [PinInserts.FCStd]
2026-04-14 debugged insert generator. Works now for pin inserts. Socket Insert model needed.
    [PinInserts.FCStd]
2026-04-19 Added support of automatic insert generation for socket inserts.
    [D38999-26AXXXXX.FCStd, PinInserts.FCStd, SocketInserts.FCStd]
2026-04-19 worked more on the insert arrangement dimension extractor.
2026-04-20 Removed inserts from shell documents.
    [D38999-20AXXXXX.FCStd, D38999-26AXXXXX.FCStd]
2026-04-20 removed insert exporting functions and added docstrings.
2026-04-20 reduced crimp clearance diameter to reduce print stability issues. Needs testing!
    [PinInserts.FCStd, SocketInserts.FCStd]
2026-04-21 Added model and generator for tolerance tests.
    [insert_tolerance_test.FCStd]
2026-04-21 Added chamfers to the print face.
    [D38999-20AXXXXX.FCStd, D38999-26AXXXXX.FCStd]
2026-04-21 Adjusted shell interface area for tighter fit. In testing!
    [PinInserts.FCStd, Pin_Insert.FCStd, SocketInserts.FCStd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]
2026-05-06 Excluded images for printables
2026-05-06 Rearranged export scheme to go after shell sizes
    [D38999-20AXXXXX.FCStd, D38999-26AXXXXX.FCStd, connector_assembly.FCStd]
